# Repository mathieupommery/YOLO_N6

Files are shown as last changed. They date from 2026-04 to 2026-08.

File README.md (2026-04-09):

# Edge AI Vision Board (STM32N657)

This repository contains the design files for a high-performance, low-power Edge AI development board centered around the STM32N657 microcontroller. This project serves as a preliminary test platform for implementing high-speed differential and parallel buses (MIPI CSI-2 and Octo-SPI) in a compact form factor.

The primary objective is to execute YOLO-based object detection models efficiently, with data output and control interfacing managed via UART.

## Hardware Overview

### Board Images

| Front View | Back View |
| :--- | :--- |
|front|back|

### Core Components

* **MCU:** STM32N657IO (High-performance Arm Cortex-M7 with integrated NPU)
* **External Memory (PSRAM):** 64MB Octo-SPI DTR (running at 200MHz)
* **External Storage (Flash):** 256MB Octo-SPI
    * *Note: PSRAM and Flash are multiplexed on a HyperBus and connected via a daisy-chain topology.*

### Peripherals & Connectivity

* **Camera:** MIPI CSI connector, pin-compatible with the Raspberry Pi 5 camera.
* **Display:** Integrated ST7789 SPI display.
* **Storage:** MicroSD card connector, supporting up to 50MHz mode.
* **Debug:** Dedicated debug connector.
* **Data & Power:** USB-C connector.
* **Communication:** UART connector.

## Design Details & Constraints

This design was simulated using IBIS models to ensure signal integrity across all high-speed interfaces.

### Signal Integrity Metrics

* **MIPI CSI-2:**
    * Inter-pair skew: Matched to ±30ps.
    * Intra-pair skew: Matched to <0.1ps.
* **Octo-SPI:**
    * MCU to PSRAM : 8ps skew tolerance.
    * MCU to Flash : 70ps skew tolerance.
* **Layout:** The "3H rule" was strictly implemented throughout the entire board layout, including between meandering differential pairs, to minimize crosstalk.

## Project Roadmap

This project is a stepping stone towards developing more complex hardware. Following successful verification of this prototype, the next iteration is planned to feature LPDDR4 memory integrated with an STM32MP257F MPU in a similar form factor.

---

**Contact:** [Pommery Mathieu]

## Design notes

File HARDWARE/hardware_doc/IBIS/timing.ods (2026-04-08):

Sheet: Feuille1
PIN | AFTER(ESD) | BEFORE(ESD) | TOT | Correc for after esd trace | AFTER_RES_CLK
DAT0 | 105,47 | 22,57 | 128,04 | 137,12
DAT1 | 114,2 | 27,29 | 141,49 | 132,4
DAT2 | 129,12 | 30,57 | 159,69 | 129,12
DAT3 | 122,75 | 26,02 | 148,77 | 133,67
CLK | 115,2 | 15,96 | 131,16 | 133,05 | 10,68
CMD | 130,72 | 21,95 | 152,67 | 137,74

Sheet: Feuille2
CSI(PIN) | DIE ibs | FCU | BCU
D0N
D0P
D1N
D1P
CLKN
CLKP

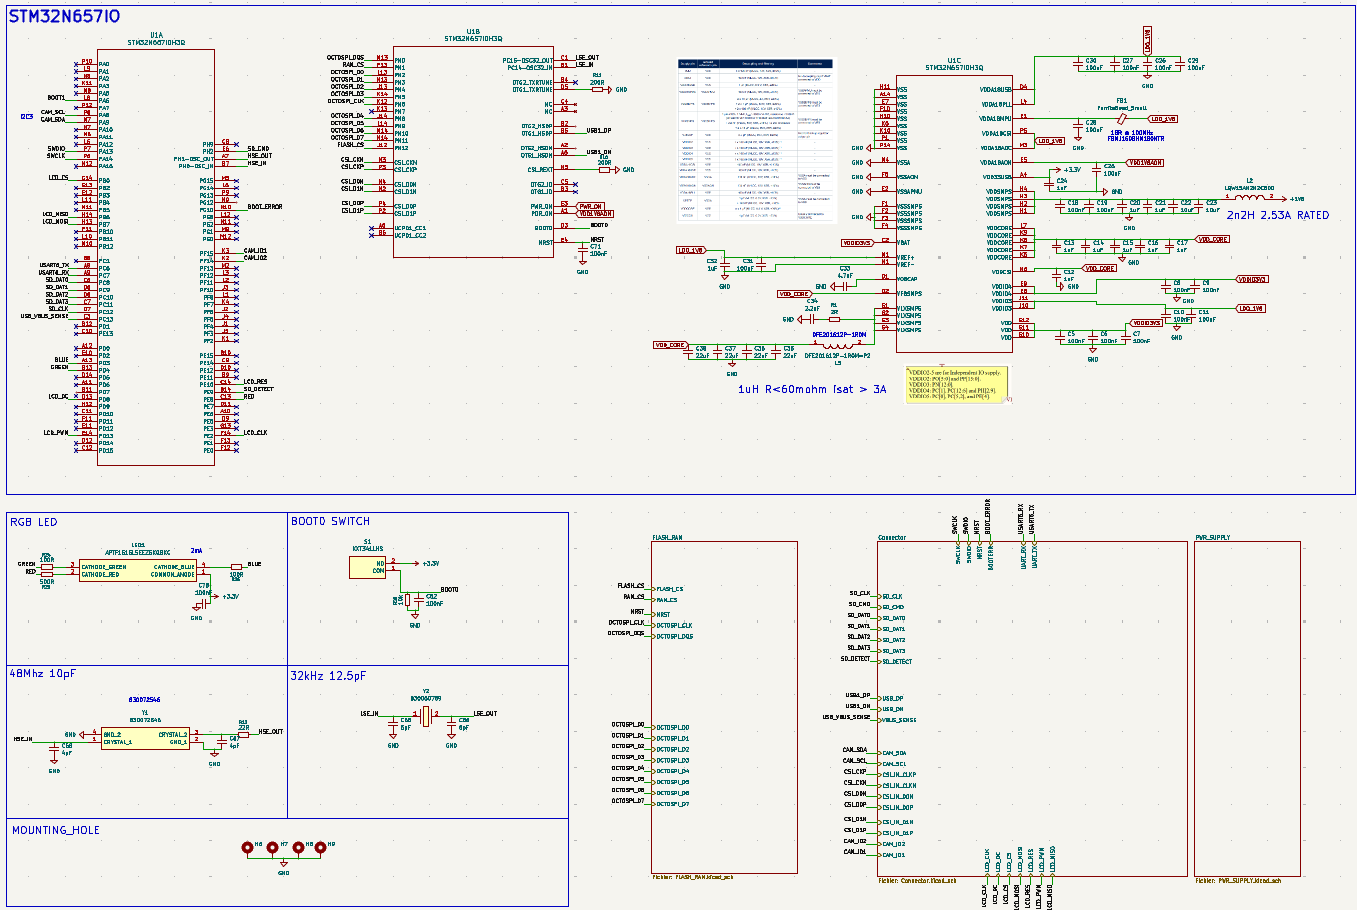
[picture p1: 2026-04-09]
DOC/stm32.png

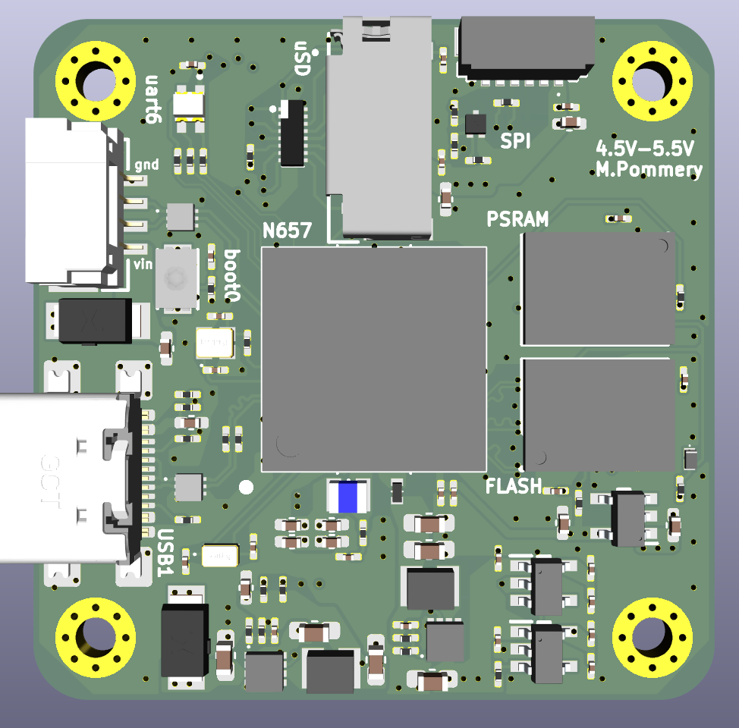
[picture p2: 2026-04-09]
DOC/front.png

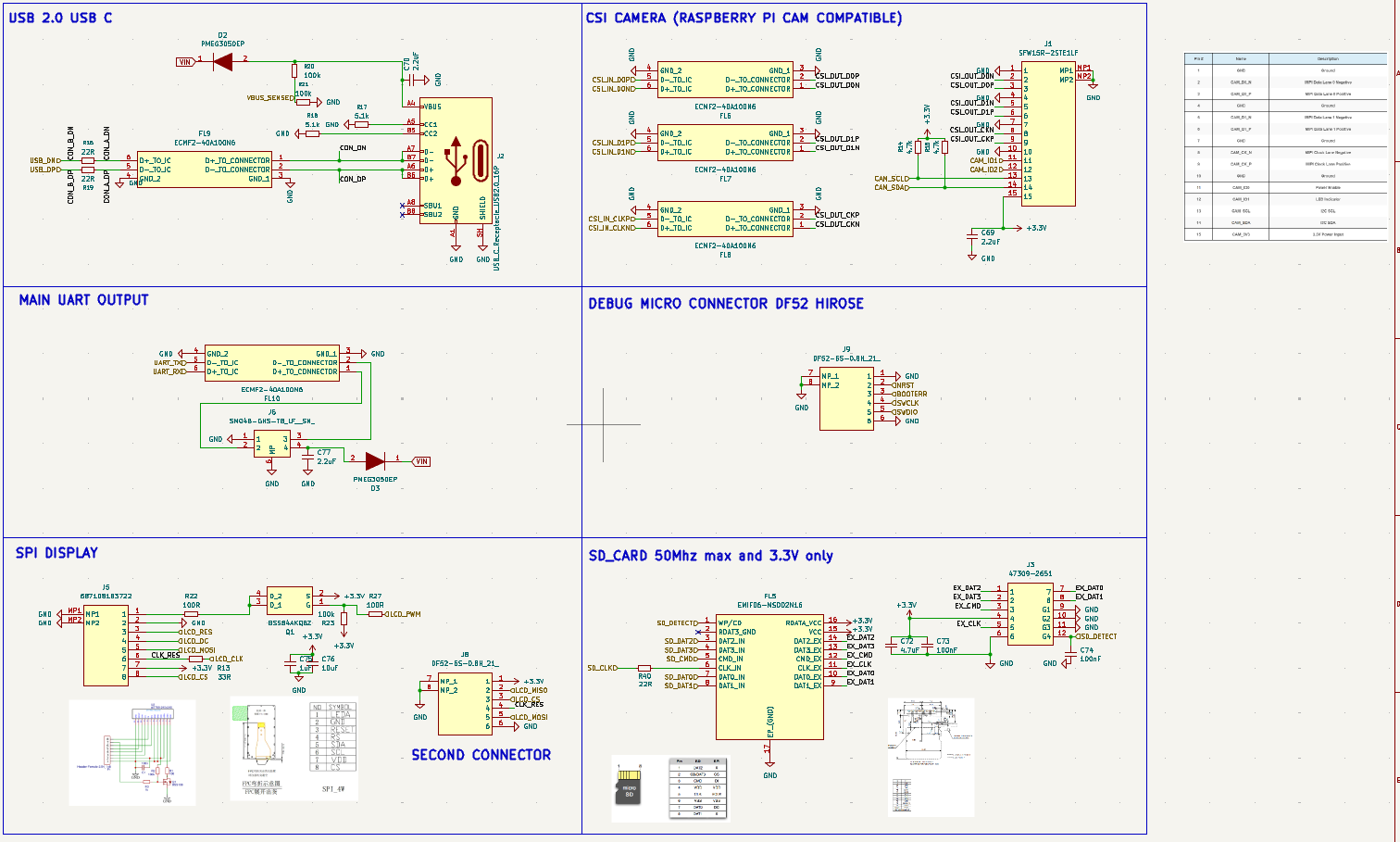
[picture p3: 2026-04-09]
DOC/conn.png

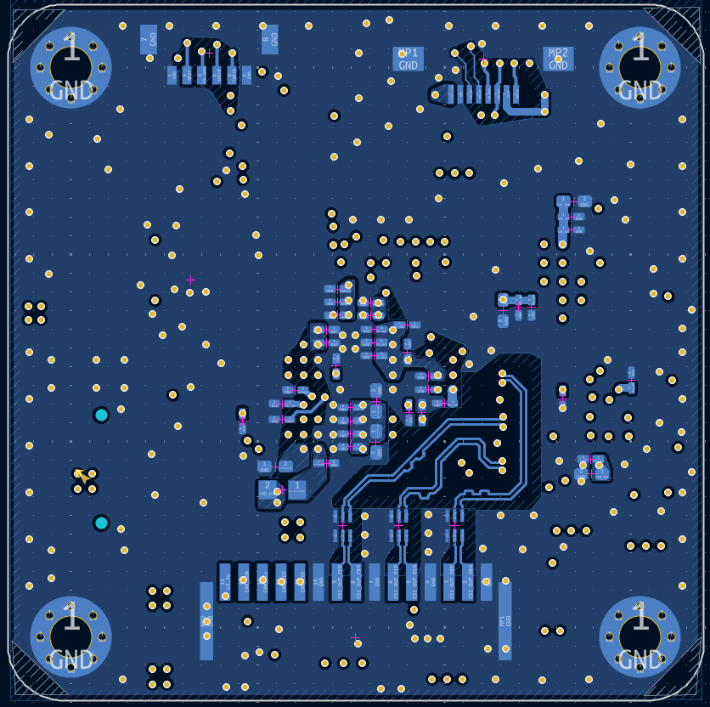
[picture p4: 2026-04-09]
DOC/l8.png

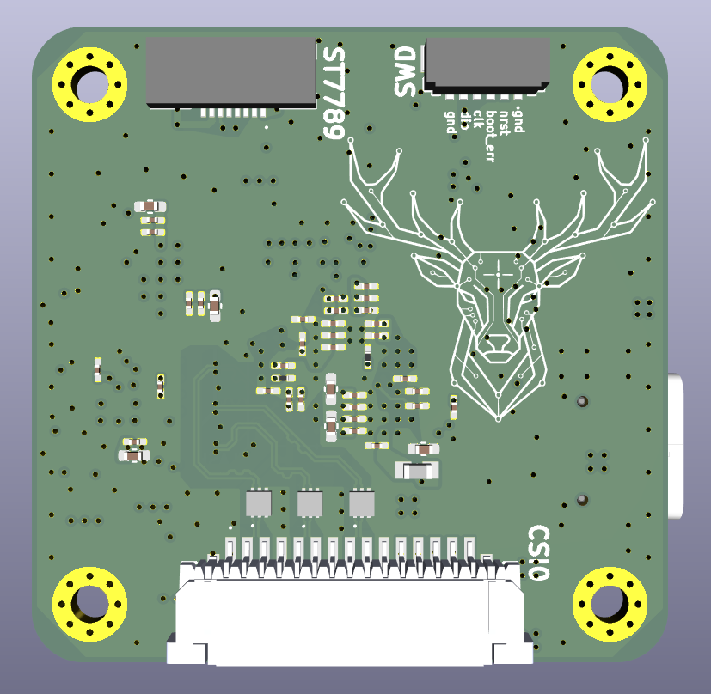
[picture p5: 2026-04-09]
DOC/back.png

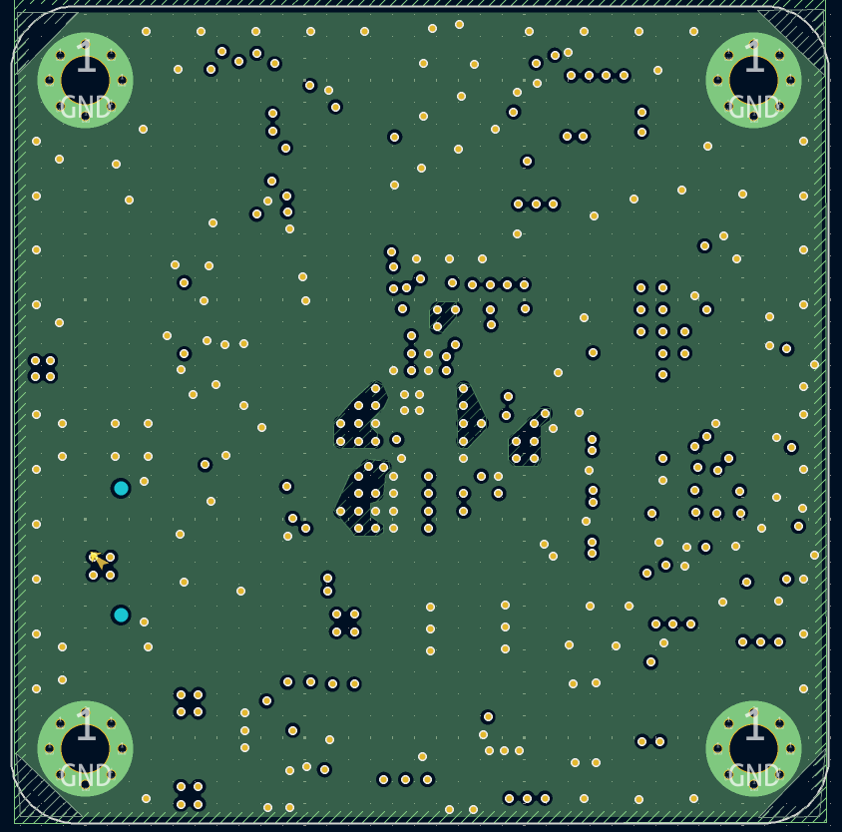
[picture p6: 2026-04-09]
DOC/l2.png

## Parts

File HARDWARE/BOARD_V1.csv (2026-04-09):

Reference | Qty | Value | Footprint
C5,C6,C7,C8,C9,C10,C11,C18,C19,C25,C26,C27,C28,C29,C30,C31,C55,C56,C57,C59,C61,C71,C73,C74,C78,C82 | 26 | 100nF | Capacitor_SMD:C_0201_0603Metric_Pad0.64x0.40mm_HandSolder
C12,C13,C14,C15,C16,C17,C20,C21,C24,C32,C39,C40,C41,C42,C43,C44,C63,C64,C75 | 19 | 1uF | Capacitor_SMD:C_0201_0603Metric_Pad0.64x0.40mm_HandSolder
C22,C23,C45,C46,C58,C60,C62,C76 | 8 | 10uF | Capacitor_SMD:C_0402_1005Metric_Pad0.74x0.62mm_HandSolder
C33,C72 | 2 | 4.7uF | Capacitor_SMD:C_0402_1005Metric_Pad0.74x0.62mm_HandSolder
C34 | 1 | 2.2nF | Capacitor_SMD:C_0201_0603Metric_Pad0.64x0.40mm_HandSolder
C35,C36,C37,C38 | 4 | 22uF | Capacitor_SMD:C_0402_1005Metric_Pad0.74x0.62mm_HandSolder
C47,C49,C50,C51,C53,C54 | 6 | 22uF | Capacitor_SMD:C_0603_1608Metric_Pad1.08x0.95mm_HandSolder
C48,C52 | 2 | 22pF | Capacitor_SMD:C_0201_0603Metric_Pad0.64x0.40mm_HandSolder
C65,C66 | 2 | 6pF | Capacitor_SMD:C_0201_0603Metric_Pad0.64x0.40mm_HandSolder
C67,C68 | 2 | 4pF | Capacitor_SMD:C_0201_0603Metric_Pad0.64x0.40mm_HandSolder
C69,C70,C77 | 3 | 2.2uF | Capacitor_SMD:C_0402_1005Metric_Pad0.74x0.62mm_HandSolder
C79,C80,C81 | 3 | 10nF | Capacitor_SMD:C_0201_0603Metric_Pad0.64x0.40mm_HandSolder
D1 | 1 | NSR05F30NXT5G | samacsys2:NSR05F30NXT5G
D2,D3 | 2 | PMEG3050EP | samacsys2:SOD4725X110N
FB1 | 1 | FBMJ1608HM180NTR | samacsys2:BEADC1608X100N
FL5 | 1 | EMIF06-MSD02N16 | samacsys2:EMIF06MSD02N16
FL6,FL7,FL8,FL9,FL10 | 5 | ECMF2-40A100N6 | samacsys2:ECMF240A100N6
IC1,IC5 | 2 | AP3441LSHE-7B | samacsys2:AP3441LSHE7B
IC2,IC3,IC4 | 3 | LDLN025M33R | samacsys2:SOT95P280X145-5N
IC6 | 1 | MX25UM25645GXDI00-T | samacsys2:BGA24C100P5X5_600X800X120
IC7 | 1 | APS51208N-OBR-BD | samacsys2:BGA24C100P5X5_600X800X120
J1 | 1 | SFW15R-2STE1LF | samacsys2:SFW15R2STE1LF
J2 | 1 | USB_C_Receptacle_USB2.0_16P | Connector_USB:USB_C_Receptacle_GCT_USB4110
J3 | 1 | 47309-2651 | samacsys:473092651
J5 | 1 | 687108183722 | samacsys:687108183722
J6 | 1 | SM04B-GHS-TB_LF__SN_ | SM04B-GHS-TB
J8,J9 | 2 | DF52-6S-0.8H_21_ | DF526S08H21
L1,L4 | 2 | 74479325207222 | samacsys2:74479325207222
L2 | 1 | LQW15AN2N2C80D | samacsys2:LQW15AN10NG80D
L5 | 1 | DFE201612P-1R0M=P2 | samacsys2:1286ASH1R0MP2
LED1 | 1 | APTF1616LSEEZGKQBKC | APTF1616SEEZGQBDC
Q1 | 1 | BSS84AKQBZ | samacsys:2N7002KQBZ
R1 | 1 | 2R | Resistor_SMD:R_0201_0603Metric_Pad0.64x0.40mm_HandSolder
R2,R6,R7,R20,R21,R23 | 6 | 100k | Resistor_SMD:R_0201_0603Metric_Pad0.64x0.40mm_HandSolder
R3 | 1 | 91k | Resistor_SMD:R_0201_0603Metric_Pad0.64x0.40mm_HandSolder
R4 | 1 | 20k | Resistor_SMD:R_0201_0603Metric_Pad0.64x0.40mm_HandSolder
R5 | 1 | 200k | Resistor_SMD:R_0201_0603Metric_Pad0.64x0.40mm_HandSolder
R8,R9,R28 | 3 | 10k | Resistor_SMD:R_0201_0603Metric_Pad0.64x0.40mm_HandSolder
R10,R11 | 2 | 200R | Resistor_SMD:R_0201_0603Metric_Pad0.64x0.40mm_HandSolder
R12,R16,R19,R40 | 4 | 22R | Resistor_SMD:R_0201_0603Metric_Pad0.64x0.40mm_HandSolder
R13 | 1 | 33R | Resistor_SMD:R_0201_0603Metric_Pad0.64x0.40mm_HandSolder
R14,R15 | 2 | 4.7k | Resistor_SMD:R_0201_0603Metric_Pad0.64x0.40mm_HandSolder
R17,R18 | 2 | 5.1k | Resistor_SMD:R_0201_0603Metric_Pad0.64x0.40mm_HandSolder
R22,R24,R26,R27 | 4 | 100R | Resistor_SMD:R_0201_0603Metric_Pad0.64x0.40mm_HandSolder
R25 | 1 | 500R | Resistor_SMD:R_0201_0603Metric_Pad0.64x0.40mm_HandSolder
S1 | 1 | KXT341LHS | KXT341LHS
U1 | 1 | STM32N657I0H3Q | STM32N657IO:VFBGA178_12X12_STM
Y1 | 1 | 830072546 | samacsys2:830072546
Y2 | 1 | 830050789 | samacsys2:830050789

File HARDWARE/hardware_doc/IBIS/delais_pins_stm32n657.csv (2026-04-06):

Pin | Signal | Inductance_nH | Capacitance_pF | Delay_ps
A1 | PDR_ON | 2.79 | 0.884 | 49.661
A2 | OTG2_HSDM | 2.894 | 0.907 | 51.226
A3 | NC | 3.026 | 0.897 | 52.101
A4 | VDD33USB | 1.346 | 1.759 | 48.658
A5 | OTG1_HSDM | 2.262 | 0.711 | 40.094
A6 | UCPD1_CC1 | 2.183 | 0.685 | 38.675
A7 | PH1-OSC_OUT | 1.998 | 0.684 | 36.964
A8 | PC6 | 2.307 | 0.695 | 40.046
A9 | PC7 | 2.13 | 0.703 | 38.692
A10 | PE6 | 2.346 | 0.731 | 41.403
A11 | PD6 | 2.614 | 0.804 | 45.836
A12 | PD0 | 2.908 | 0.922 | 51.776
A13 | PD3 | 3.172 | 0.97 | 55.483
A14 | VSS | 0.046 | 58.495 | 52.064
B1 | PC14 | 2.793 | 0.876 | 49.462
B2 | OTG2_HSDP | 2.677 | 0.89 | 48.821
B3 | OTG1_ID | 2.639 | 0.924 | 49.376
B4 | OTG2_TXRTUNE | 1.941 | 0.669 | 36.049
B5 | OTG1_HSDP | 2.207 | 0.696 | 39.191
B6 | UCPD1_CC2 | 1.665 | 0.613 | 31.952
B7 | PH0-OSC_IN | 1.582 | 0.568 | 29.985
B8 | PC1 | 1.982 | 0.651 | 35.924
B9 | PE11 | 1.847 | 0.59 | 33.018
B10 | PE15 | 2.157 | 0.666 | 37.908
B11 | PD7 | 2.215 | 0.72 | 39.934
B12 | PD1 | 2.146 | 0.737 | 39.769
B13 | PD4 | 2.802 | 0.874 | 49.494
B14 | PE9 | 3.05 | 0.943 | 53.644
C1 | PC15-OSC32_OUT | 2.788 | 0.87 | 49.257
C2 | VBAT | 2.11 | 0.774 | 40.407
C3 | PC13 | 1.901 | 0.701 | 36.509
C4 | NC | 1.477 | 0.658 | 31.168
C5 | OTG2_ID | 1.265 | 0.537 | 26.065
C6 | PC8 | 2.797 | 0.814 | 47.729
C7 | PC11 | 2.052 | 0.609 | 35.356
C8 | PH9 | 1.474 | 0.525 | 27.813
C9 | PE14 | 1.582 | 0.603 | 30.89
C10 | PE13 | 1.579 | 0.52 | 28.66
C11 | PD10 | 1.724 | 0.612 | 32.489
C12 | PD15 | 2.107 | 0.708 | 38.637
C13 | PE8 | 2.451 | 0.773 | 43.533
C14 | PE10 | 2.737 | 0.862 | 48.562
D1 | V08CAP | 2.209 | 0.8 | 42.041
D2 | VFBSMPS | 2.669 | 0.898 | 48.949
D3 | BOOT0 | 1.459 | 0.491 | 26.777
D4 | VDDA18USB | 1.107 | 1.38 | 39.093
D5 | OTG1_TXRTUNE | 2.055 | 0.696 | 37.806
D6 | PC9 | 2.959 | 0.859 | 50.402
D7 | PC12 | 1.824 | 0.58 | 32.529
D8 | PC10 | 0.924 | 0.415 | 19.581
D9 | PE5 | 1.376 | 0.535 | 27.141
D10 | PE12 | 1.227 | 0.504 | 24.856
D11 | PE7 | 1.39 | 0.517 | 26.81
D12 | PD14 | 1.715 | 0.576 | 31.413
D13 | PD8 | 2.038 | 0.655 | 36.541
D14 | PD5 | 2.558 | 0.791 | 44.974
E1 | VDDA18PMU | 2.027 | 0.757 | 39.167
E2 | VSSAPMU | 1.583 | 0.645 | 31.942
E3 | PWR_ON | 1.204 | 0.47 | 23.794
E4 | NRST | 0.898 | 0.41 | 19.192
E5 | VDDA18AON | 0.281 | 4.532 | 35.69
E6 | PH2 | 2.586 | 0.732 | 43.522
E8 | VDDIO4 | 0.196 | 0.708 | 11.767
E10 | PD2 | 0.786 | 0.401 | 17.756
E11 | PD12 | 0.99 | 0.411 | 20.18
E12 | PB3 | 1.732 | 0.615 | 32.626
E13 | PB2 | 2.019 | 0.666 | 36.656
E14 | PD13 | 2.575 | 0.812 | 45.736
F1 | VSSSMPS | 0.317 | 1.553 | 22.188
F5 | VSSAON | 0.936 | 0.457 | 20.678
F11 | PD11 | 1.762 | 0.654 | 33.936
F12 | PE0 | 1.586 | 0.625 | 31.493
F13 | PE1 | 1.683 | 0.606 | 31.94
F14 | PE2 | 2.121 | 0.693 | 38.331
G1 | VLXSMPS | 0.273 | 1.437 | 19.818
G10 | VDD | 0.395 | 3.614 | 37.779
G13 | PE3 | 1.577 | 0.559 | 29.681
G14 | PB0 | 1.936 | 0.655 | 35.611
H1 | VDDSMPS | 0.264 | 1.433 | 19.442
H12 | PD9 | 0.916 | 0.423 | 19.686
H13 | PB7 | 1.487 | 0.557 | 28.777
H14 | PB6 | 2.015 | 0.682 | 37.085
J1 | PF4 | 1.762 | 0.622 | 33.101
J2 | PF6 | 1.603 | 0.567 | 30.151
J3 | PF10 | 1.138 | 0.43 | 22.119
J4 | PF5 | 0.678 | 0.298 | 14.201
J5 | PF3 | 0.907 | 0.435 | 19.873
J10 | VDDIO3 | 0.53 | 1.583 | 28.956
J12 | PN12 | 4.208 | 1.211 | 71.388
J13 | PN4 | 2.346 | 0.698 | 40.469
J14 | PN8 | 3.919 | 1.097 | 65.579
K1 | PF2 | 2.15 | 0.683 | 38.314
K2 | PF14 | 1.753 | 0.591 | 32.204
K3 | PF15 | 1.272 | 0.472 | 24.493
K4 | PF7 | 1.05 | 0.452 | 21.794
K6 | VDDCORE | 0.081 | 6.305 | 22.612
K11 | PA3 | 2.747 | 0.911 | 50.041
K12 | PN6 | 2.077 | 0.703 | 38.226
K13 | PN7 | 2.776 | 0.828 | 47.95
K14 | PN5 | 2.641 | 0.776 | 45.27
L1 | PF8 | 2.243 | 0.694 | 39.469
L2 | PF11 | 1.908 | 0.614 | 34.244
L3 | PF12 | 1.404 | 0.473 | 25.767
L4 | VDDA18PLL | 3.343 | 1.393 | 68.255
L5 | PG14 | 2.257 | 0.725 | 40.461
L6 | PA12 | 1.335 | 0.537 | 26.781
L8 | PA6 | 1.231 | 0.542 | 25.841
L9 | PA1 | 1.96 | 0.663 | 36.054
L10 | PB11 | 2.297 | 0.719 | 40.632
L11 | PB4 | 2.864 | 0.831 | 48.798
L12 | PG8 | 2.902 | 0.904 | 51.211
L13 | PN2 | 2.336 | 0.703 | 40.521
L14 | PN9 | 3.226 | 0.925 | 54.637
M1 | VREFP | 2.652 | 0.871 | 48.057
M2 | PF13 | 2.045 | 0.617 | 35.518
M3 | VDDA18ADC | 1.123 | 1.118 | 35.44
M4 | VSSA | 1.033 | 0.976 | 31.742
M5 | PG15 | 2.12 | 0.715 | 38.924
M6 | PA11 | 1.414 | 0.52 | 27.122
M7 | PA9 | 1.132 | 0.44 | 22.317
M8 | PA5 | 1.516 | 0.586 | 29.811
M9 | PG1 | 1.931 | 0.655 | 35.562
M10 | PB12 | 2.193 | 0.68 | 38.607
M11 | PB5 | 2.716 | 0.815 | 47.054
M12 | PG0 | 2.79 | 0.811 | 47.563
M13 | PN0 | 3.065 | 0.842 | 50.788
M14 | PN10 | 3.031 | 0.888 | 51.883
N1 | VREFM | 2.44 | 0.857 | 45.72
N2 | CSI_D1N | 2.302 | 0.836 | 43.868
N3 | CSI_CKN | 2.325 | 0.802 | 43.183
N4 | CSI_D0N | 2.183 | 0.747 | 40.392
N5 | CSI_REXT | 1.929 | 0.685 | 36.34
N6 | VDDCSI | 1.488 | 0.63 | 30.609
N7 | PA10 | 1.702 | 0.578 | 31.38
N8 | PA2 | 1.861 | 0.675 | 35.447
N9 | PG12 | 2.067 | 0.646 | 36.532
N10 | PG10 | 2.347 | 0.769 | 42.493
N11 | PG2 | 2.558 | 0.806 | 45.411
N12 | PA15 | 2.854 | 0.814 | 48.196
N13 | PN3 | 4.025 | 1.156 | 68.203
N14 | PN11 | 2.794 | 0.919 | 50.668
P2 | CSI_D1P | 2.407 | 0.84 | 44.973
P3 | CSI_CKP | 2.327 | 0.819 | 43.639
P4 | CSI_D0P | 2.18 | 0.772 | 41.035
P5 | VDDA18CSI | 1.983 | 0.768 | 39.027
P6 | PA14 | 1.904 | 0.663 | 35.532
P7 | PA13 | 2.264 | 0.732 | 40.707
P8 | PA8 | 2.117 | 0.669 | 37.64
P9 | PG13 | 2.264 | 0.69 | 39.513
P10 | PA0 | 2.573 | 0.762 | 44.283
P11 | PB10 | 2.606 | 0.795 | 45.51
P12 | PA7 | 3.138 | 0.876 | 52.421
P13 | PN1 | 3.535 | 0.981 | 58.875

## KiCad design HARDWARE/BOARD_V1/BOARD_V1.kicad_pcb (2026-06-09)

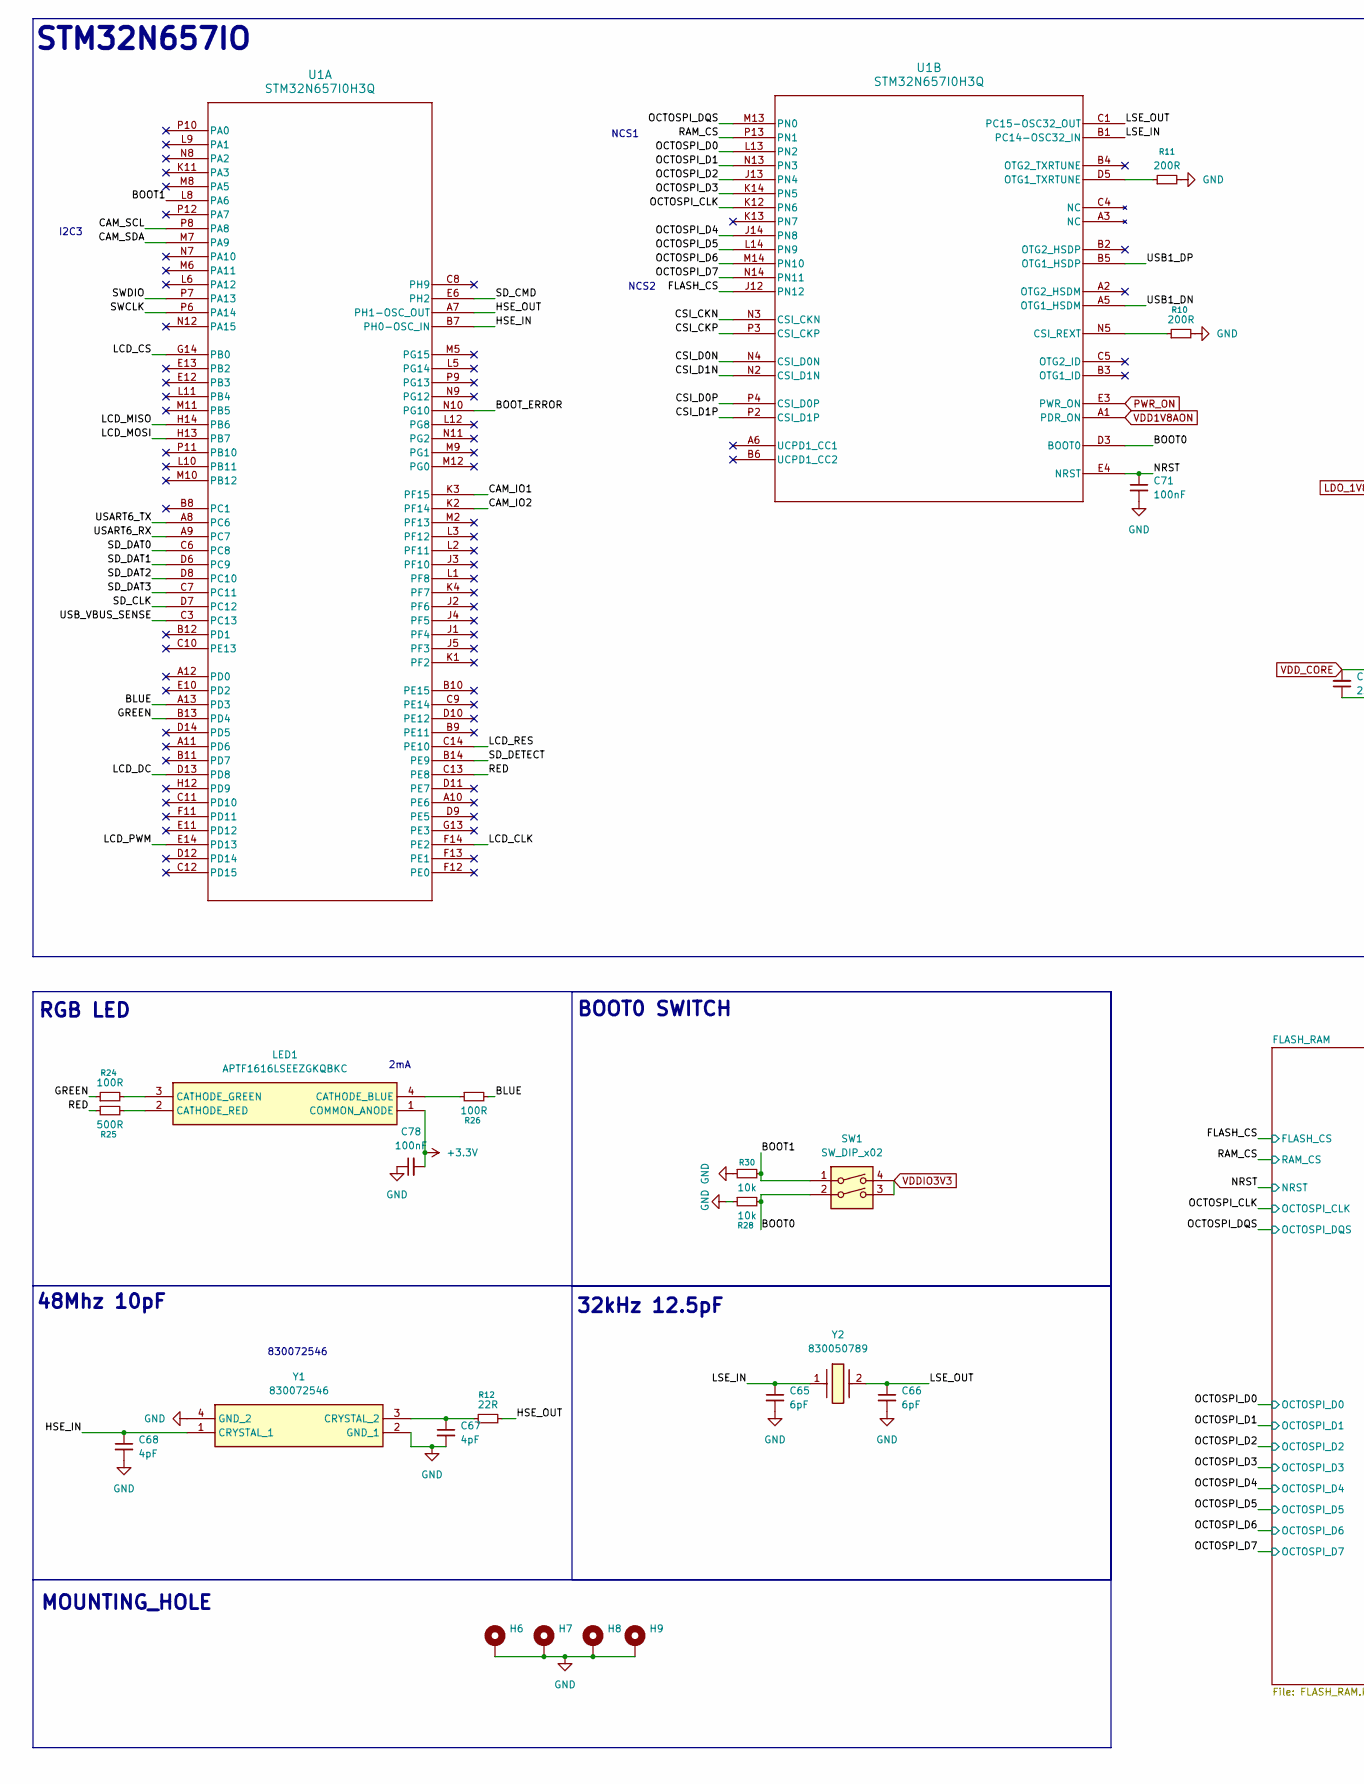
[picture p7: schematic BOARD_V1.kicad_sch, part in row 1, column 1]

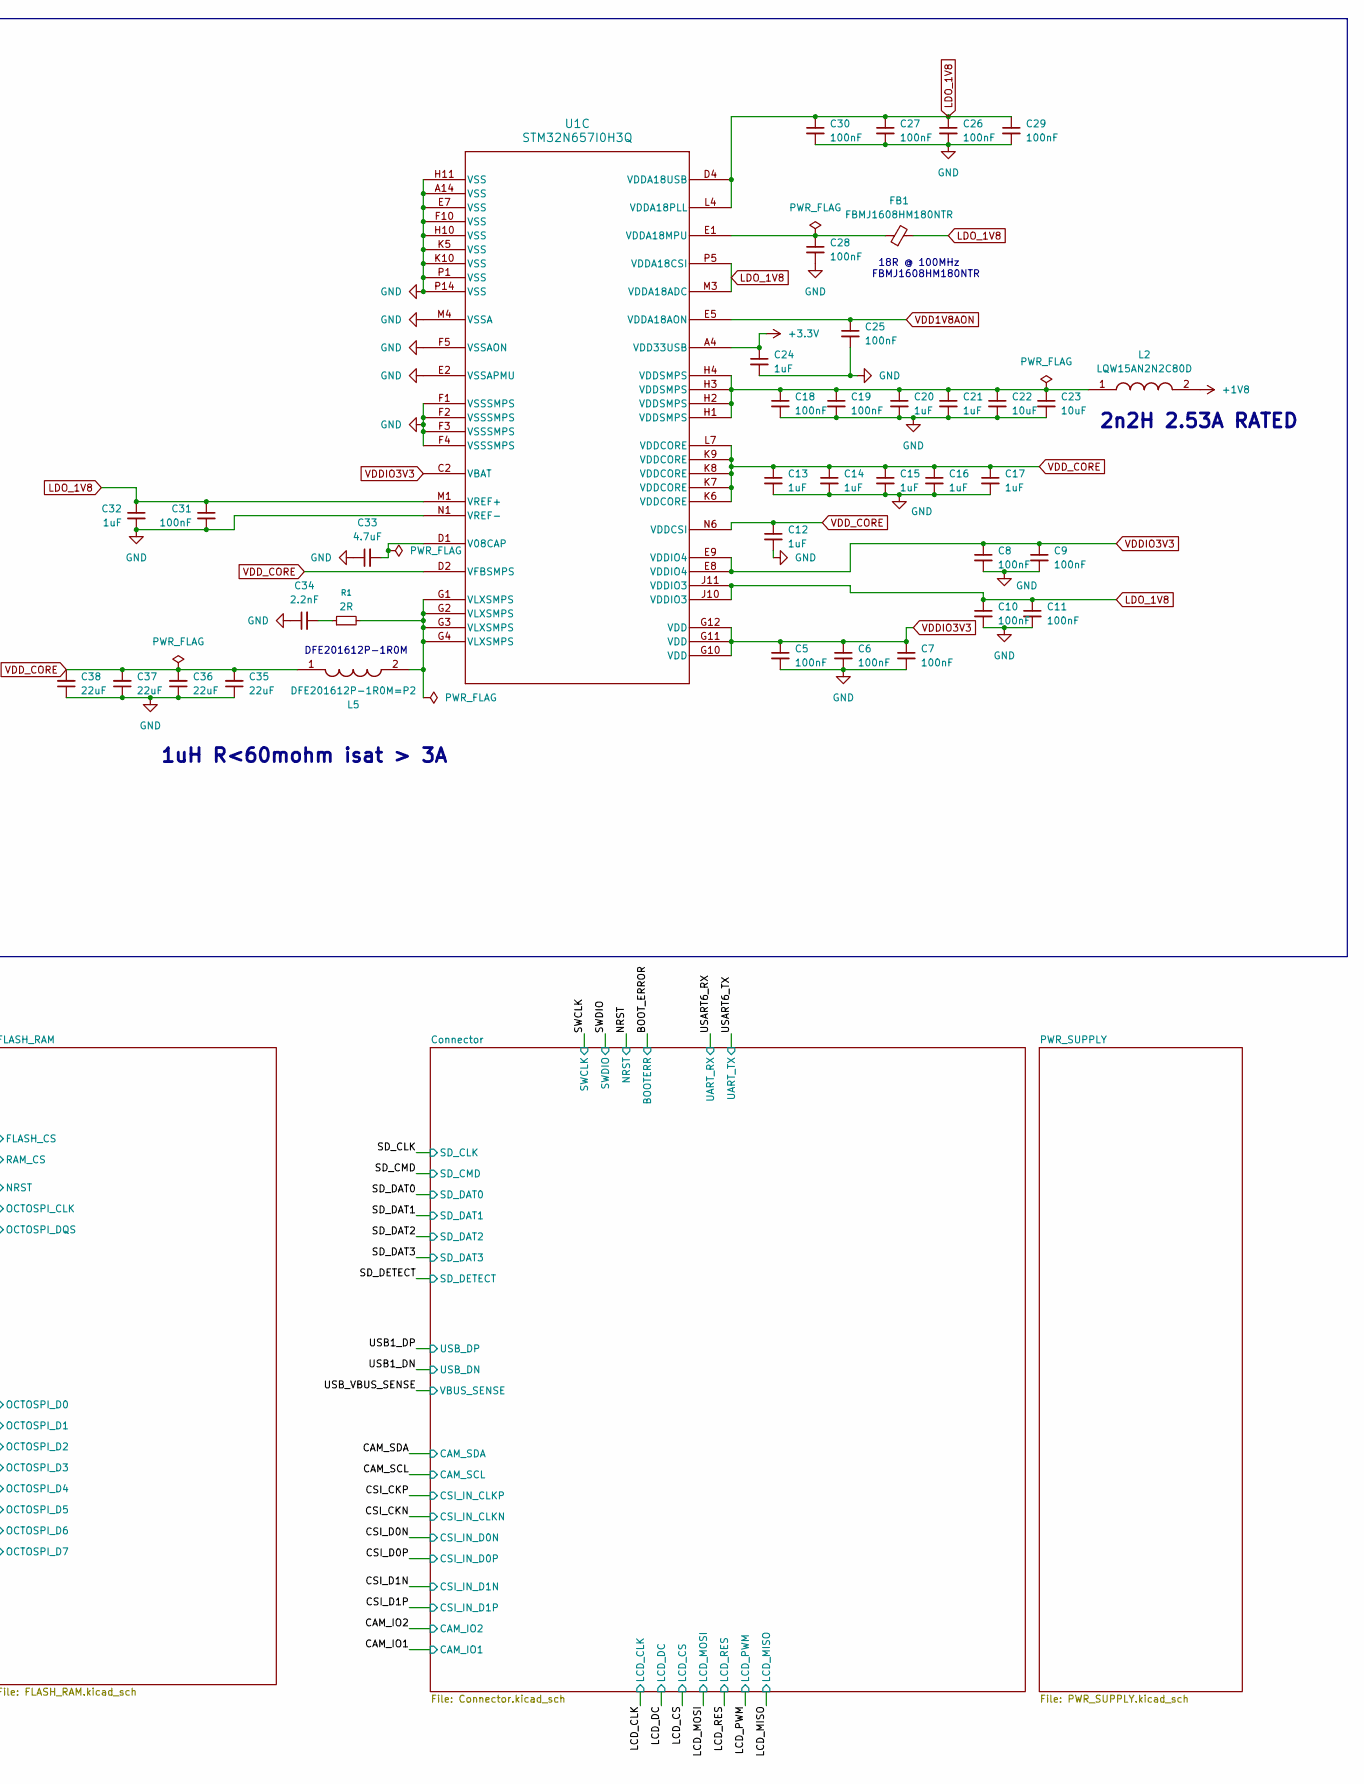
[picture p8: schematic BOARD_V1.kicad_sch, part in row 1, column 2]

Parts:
C5, C6, C7, C8, C9, C10, C11, C18, C19, C25, C26, C27, C28, C29, C30, C31, C71, C78: 100nF; C_0201_0603Metric_Pad0.64x0.40mm_HandSolder
C12, C13, C14, C15, C16, C17, C20, C21, C24, C32: 1uF; C_0201_0603Metric_Pad0.64x0.40mm_HandSolder
C22, C23: 10uF; C_0402_1005Metric_Pad0.74x0.62mm_HandSolder
C33: 4.7uF; C_0402_1005Metric_Pad0.74x0.62mm_HandSolder
C34: 2.2nF; C_0201_0603Metric_Pad0.64x0.40mm_HandSolder
C35, C36, C37, C38: 22uF; C_0402_1005Metric_Pad0.74x0.62mm_HandSolder
C65, C66: 6pF; C_0201_0603Metric_Pad0.64x0.40mm_HandSolder
C67, C68: 4pF; C_0201_0603Metric_Pad0.64x0.40mm_HandSolder
FB1: FBMJ1608HM180NTR; BEADC1608X100N; Mouser Part Number 963-FBMJ1608HM180NTR
H6, H7, H8, H9: MountingHole_Pad_MP; MountingHole_2.2mm_M2_Pad_Via
L2: LQW15AN2N2C80D; LQW15AN10NG80D; Manufacturer_Part_Number LQW15AN2N2C80D; Mouser Part Number 81-LQW15AN2N2C80D
L5: DFE201612P-1R0M=P2; 1286ASH1R0MP2; Manufacturer_Part_Number DFE201612P-1R0M=P2; Mouser Part Number 81-DFE201612P-1R0MP2
LED1: APTF1616LSEEZGKQBKC; APTF1616SEEZGQBDC; Manufacturer_Part_Number APTF1616LSEEZGKQBKC; Mouser Part Number 604-APTF1616LSEEZGKQ
R1: 2R; R_0201_0603Metric_Pad0.64x0.40mm_HandSolder
R10, R11: 200R; R_0201_0603Metric_Pad0.64x0.40mm_HandSolder
R12: 22R; R_0201_0603Metric_Pad0.64x0.40mm_HandSolder
R24, R26: 100R; R_0201_0603Metric_Pad0.64x0.40mm_HandSolder
R25: 500R; R_0201_0603Metric_Pad0.64x0.40mm_HandSolder
R28, R30: 10k; R_0201_0603Metric_Pad0.64x0.40mm_HandSolder
SW1: SW_DIP_x02; SW_DIP_SPSTx02_Slide_KingTek_DSHP02TJ_W5.25mm_P1.27mm_JPin
U1: STM32N657I0H3Q; VFBGA178_12X12_STM
Y1: 830072546; Manufacturer_Part_Number 830072546; Mouser Part Number 710-830072546
Y2: 830050789; Manufacturer_Part_Number 830050789; Mouser Part Number 710-830050789

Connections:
+1V8: L2.2; also elsewhere on the board
+3.3V: C24.1, C78.2, LED1.1 (COMMON_ANODE), U1.A4 (VDD33USB); also elsewhere on the board
/BLUE: R26.2, U1.A13 (PD3)
/BOOT0: R28.2, SW1.2, U1.D3 (BOOT0)
/BOOT1: R30.2, SW1.1, U1.L8 (PA6)
/BOOT_ERROR: U1.N10 (PG10); also elsewhere on the board
/CAM_IO1: U1.K3 (PF15); also elsewhere on the board
/CAM_IO2: U1.K2 (PF14); also elsewhere on the board
/CAM_SCL: U1.P8 (PA8); also elsewhere on the board
/CAM_SDA: U1.M7 (PA9); also elsewhere on the board
/CSI_CKN: U1.N3 (CSI_CKN); also elsewhere on the board
/CSI_CKP: U1.P3 (CSI_CKP); also elsewhere on the board
/CSI_D0N: U1.N4 (CSI_D0N); also elsewhere on the board
/CSI_D0P: U1.P4 (CSI_D0P); also elsewhere on the board
/CSI_D1N: U1.N2 (CSI_D1N); also elsewhere on the board
/CSI_D1P: U1.P2 (CSI_D1P); also elsewhere on the board
/FLASH_CS: U1.J12 (PN12); also elsewhere on the board
/GREEN: R24.1, U1.B13 (PD4)
/HSE_IN: C68.1, U1.B7 (PH0-OSC_IN), Y1.1 (CRYSTAL_1)
/HSE_OUT: R12.2, U1.A7 (PH1-OSC_OUT)
/LCD_CLK: U1.F14 (PE2); also elsewhere on the board
/LCD_CS: U1.G14 (PB0); also elsewhere on the board
/LCD_DC: U1.D13 (PD8); also elsewhere on the board
/LCD_MISO: U1.H14 (PB6); also elsewhere on the board
/LCD_MOSI: U1.H13 (PB7); also elsewhere on the board
/LCD_PWM: U1.E14 (PD13); also elsewhere on the board
/LCD_RES: U1.C14 (PE10); also elsewhere on the board
/LSE_IN: C65.1, U1.B1 (PC14-OSC32_IN), Y2.1
/LSE_OUT: C66.1, U1.C1 (PC15-OSC32_OUT), Y2.2
/NRST: C71.1, U1.E4 (NRST); also elsewhere on the board
/OCTOSPI_CLK: U1.K12 (PN6); also elsewhere on the board
/OCTOSPI_D0: U1.L13 (PN2); also elsewhere on the board
/OCTOSPI_D1: U1.N13 (PN3); also elsewhere on the board
/OCTOSPI_D2: U1.J13 (PN4); also elsewhere on the board
/OCTOSPI_D3: U1.K14 (PN5); also elsewhere on the board
/OCTOSPI_D4: U1.J14 (PN8); also elsewhere on the board
/OCTOSPI_D5: U1.L14 (PN9); also elsewhere on the board
/OCTOSPI_D6: U1.M14 (PN10); also elsewhere on the board
/OCTOSPI_D7: U1.N14 (PN11); also elsewhere on the board
/OCTOSPI_DQS: U1.M13 (PN0); also elsewhere on the board
/RAM_CS: U1.P13 (PN1); also elsewhere on the board
/RED: R25.1, U1.C13 (PE8)
/SD_CLK: U1.D7 (PC12); also elsewhere on the board
/SD_CMD: U1.E6 (PH2); also elsewhere on the board
/SD_DAT0: U1.C6 (PC8); also elsewhere on the board
/SD_DAT1: U1.D6 (PC9); also elsewhere on the board
/SD_DAT2: U1.D8 (PC10); also elsewhere on the board
/SD_DAT3: U1.C7 (PC11); also elsewhere on the board
/SD_DETECT: U1.B14 (PE9); also elsewhere on the board
/SWCLK: U1.P6 (PA14); also elsewhere on the board
/SWDIO: U1.P7 (PA13); also elsewhere on the board
/USART6_RX: U1.A9 (PC7); also elsewhere on the board
/USART6_TX: U1.A8 (PC6); also elsewhere on the board
/USB1_DN: U1.A5 (OTG1_HSDM); also elsewhere on the board
/USB1_DP: U1.B5 (OTG1_HSDP); also elsewhere on the board
/USB_VBUS_SENSE: U1.C3 (PC13); also elsewhere on the board
GND: C5.2, C6.2, C7.2, C8.2, C9.2, C10.2, C11.2, C12.2, C13.2, C14.2, C15.2, C16.2, C17.2, C18.2, C19.2, C20.2, C21.2, C22.2, C23.2, C24.2, C25.2, C26.2, C27.2, C28.2, C29.2, C30.2, C31.2, C32.2, C33.1, C34.1, C35.1, C36.1, C37.1, C38.1, C65.2, C66.2, C67.2, C68.2, C71.2, C78.1, H6.1 (1_1), H7.1 (1_1), H8.1 (1_1), H9.1 (1_1), R10.2, R11.2, R28.1, R30.1, U1.A14 (VSS), U1.E2 (VSSAPMU), U1.E7 (VSS), U1.F1 (VSSSMPS), U1.F2 (VSSSMPS), U1.F3 (VSSSMPS), U1.F4 (VSSSMPS), U1.F5 (VSSAON), U1.F10 (VSS), U1.H10 (VSS), U1.H11 (VSS), U1.K5 (VSS), U1.K10 (VSS), U1.M4 (VSSA), U1.N1 (VREF-), U1.P1 (VSS), U1.P14 (VSS), Y1.2 (GND_1), Y1.4 (GND_2); also elsewhere on the board
LDO_1V8: C10.1, C11.1, C26.1, C27.1, C29.1, C30.1, C31.1, C32.1, FB1.2, U1.D4 (VDDA18USB), U1.J10 (VDDIO3), U1.J11 (VDDIO3), U1.L4 (VDDA18PLL), U1.M1 (VREF+), U1.M3 (VDDA18ADC), U1.P5 (VDDA18CSI); also elsewhere on the board
unnamed: C18.1, C19.1, C20.1, C21.1, C22.1, C23.1, L2.1, U1.H1 (VDDSMPS), U1.H2 (VDDSMPS), U1.H3 (VDDSMPS), U1.H4 (VDDSMPS)
unnamed: C34.2, R1.1
unnamed: L5.2, R1.2, U1.G1 (VLXSMPS), U1.G2 (VLXSMPS), U1.G3 (VLXSMPS), U1.G4 (VLXSMPS)
unnamed: LED1.4 (CATHODE_BLUE), R26.1
unnamed: LED1.3 (CATHODE_GREEN), R24.2
unnamed: LED1.2 (CATHODE_RED), R25.2
unnamed: R10.1, U1.N5 (CSI_REXT)
unnamed: R11.1, U1.D5 (OTG1_TXRTUNE)
unnamed: C33.2, U1.D1 (V08CAP)
unnamed: C28.1, FB1.1, U1.E1 (VDDA18MPU)
unnamed: C67.1, R12.1, Y1.3 (CRYSTAL_2)
PWR_ON: U1.E3 (PWR_ON); also elsewhere on the board
VDD1V8AON: C25.1, U1.A1 (PDR_ON), U1.E5 (VDDA18AON); also elsewhere on the board
VDDIO3V3: C5.1, C6.1, C7.1, C8.1, C9.1, SW1.3, SW1.4, U1.C2 (VBAT), U1.E8 (VDDIO4), U1.E9 (VDDIO4), U1.G10 (VDD), U1.G11 (VDD), U1.G12 (VDD); also elsewhere on the board
VDD_CORE: C12.1, C13.1, C14.1, C15.1, C16.1, C17.1, C35.2, C36.2, C37.2, C38.2, L5.1, U1.D2 (VFBSMPS), U1.K6 (VDDCORE), U1.K7 (VDDCORE), U1.K8 (VDDCORE), U1.K9 (VDDCORE), U1.L7 (VDDCORE), U1.N6 (VDDCSI)

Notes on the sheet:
FBMJ1608HM180NTR
2mA
830072546
MOUNTING_HOLE
I2C3
48Mhz 10pF
1uH R<60mohm isat > 3A
RGB LED
32kHz 12.5pF
BOOT0 SWITCH
STM32N657IO
18R @ 100MHz
NCS1
DFE201612P-1R0M
NCS2
2n2H 2.53A RATED

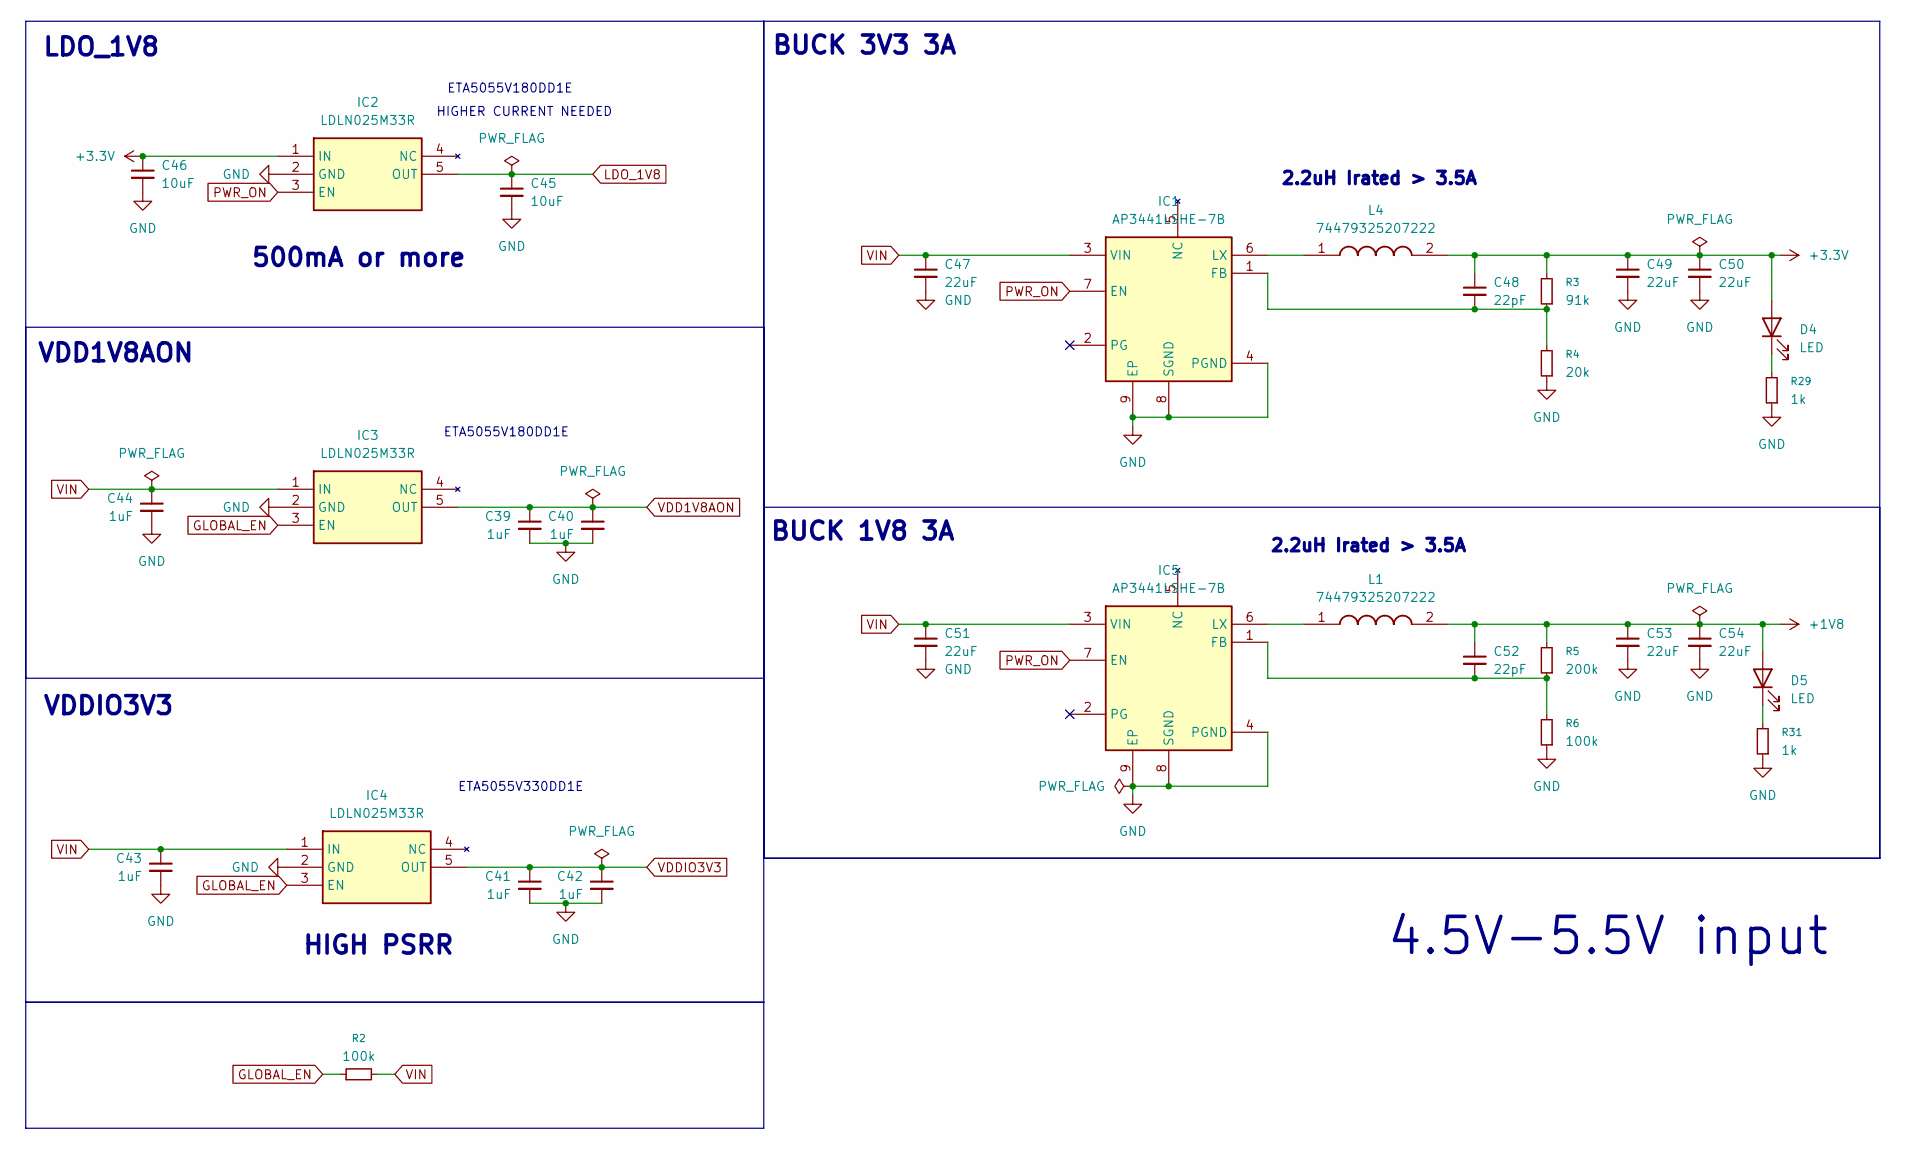
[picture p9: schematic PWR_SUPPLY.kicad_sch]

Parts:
C39, C40, C41, C42, C43, C44: 1uF; C_0201_0603Metric_Pad0.64x0.40mm_HandSolder
C45, C46: 10uF; C_0402_1005Metric_Pad0.74x0.62mm_HandSolder
C47, C49, C50, C51, C53, C54: 22uF; C_0603_1608Metric_Pad1.08x0.95mm_HandSolder
C48, C52: 22pF; C_0201_0603Metric_Pad0.64x0.40mm_HandSolder
D4, D5: LED; LED_0402_1005Metric
IC1, IC5: AP3441LSHE-7B; AP3441LSHE7B; Manufacturer_Part_Number AP3441LSHE-7B; Mouser Part Number 621-AP3441LSHE-7B
IC2, IC3, IC4: LDLN025M33R; SOT95P280X145-5N; Manufacturer_Part_Number LDLN025M33R; Mouser Part Number 511-LDLN025M33R 595-TLV75518PDBVR 511-L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
L1, L4: 74479325207222; Manufacturer_Part_Number 74479325207222
R2, R6: 100k; R_0201_0603Metric_Pad0.64x0.40mm_HandSolder
R3: 91k; R_0201_0603Metric_Pad0.64x0.40mm_HandSolder
R4: 20k; R_0201_0603Metric_Pad0.64x0.40mm_HandSolder
R5: 200k; R_0201_0603Metric_Pad0.64x0.40mm_HandSolder
R29, R31: 1k; R_0201_0603Metric_Pad0.64x0.40mm_HandSolder

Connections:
+1V8: C52.1, C53.1, C54.1, D5.2 (A), L1.2, R5.2; also elsewhere on the board
+3.3V: C46.1, C48.1, C49.1, C50.1, D4.2 (A), IC2.1 (IN), L4.2, R3.2; also elsewhere on the board
GLOBAL_EN: IC3.3 (EN), IC4.3 (EN), R2.1
GND: C39.2, C40.2, C41.2, C42.2, C43.2, C44.2, C45.2, C46.2, C47.2, C49.2, C50.2, C51.2, C53.2, C54.2, IC1.4 (PGND), IC1.8 (SGND), IC1.9 (EP), IC2.2 (GND), IC3.2 (GND), IC4.2 (GND), IC5.4 (PGND), IC5.8 (SGND), IC5.9 (EP), R4.1, R6.1, R29.1, R31.1; also elsewhere on the board
LDO_1V8: C45.1, IC2.5 (OUT); also elsewhere on the board
unnamed: D4.1 (K), R29.2
unnamed: D5.1 (K), R31.2
unnamed: C48.2, IC1.1 (FB), R3.1, R4.2
unnamed: IC1.6 (LX), L4.1
unnamed: C52.2, IC5.1 (FB), R5.1, R6.2
unnamed: IC5.6 (LX), L1.1
PWR_ON: IC1.7 (EN), IC2.3 (EN), IC5.7 (EN); also elsewhere on the board
VDD1V8AON: C39.1, C40.1, IC3.5 (OUT); also elsewhere on the board
VDDIO3V3: C41.1, C42.1, IC4.5 (OUT); also elsewhere on the board
VIN: C43.1, C44.1, C47.1, C51.1, IC1.3 (VIN), IC3.1 (IN), IC4.1 (IN), IC5.3 (VIN), R2.2; also elsewhere on the board

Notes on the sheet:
2.2uH Irated > 3.5A
BUCK 1V8 3A
4.5V-5.5V input
LDO_1V8
HIGH PSRR
BUCK 3V3 3A
ETA5055V180DD1E
ETA5055V330DD1E
VDDIO3V3
VDD1V8AON
HIGHER CURRENT NEEDED
500mA or more

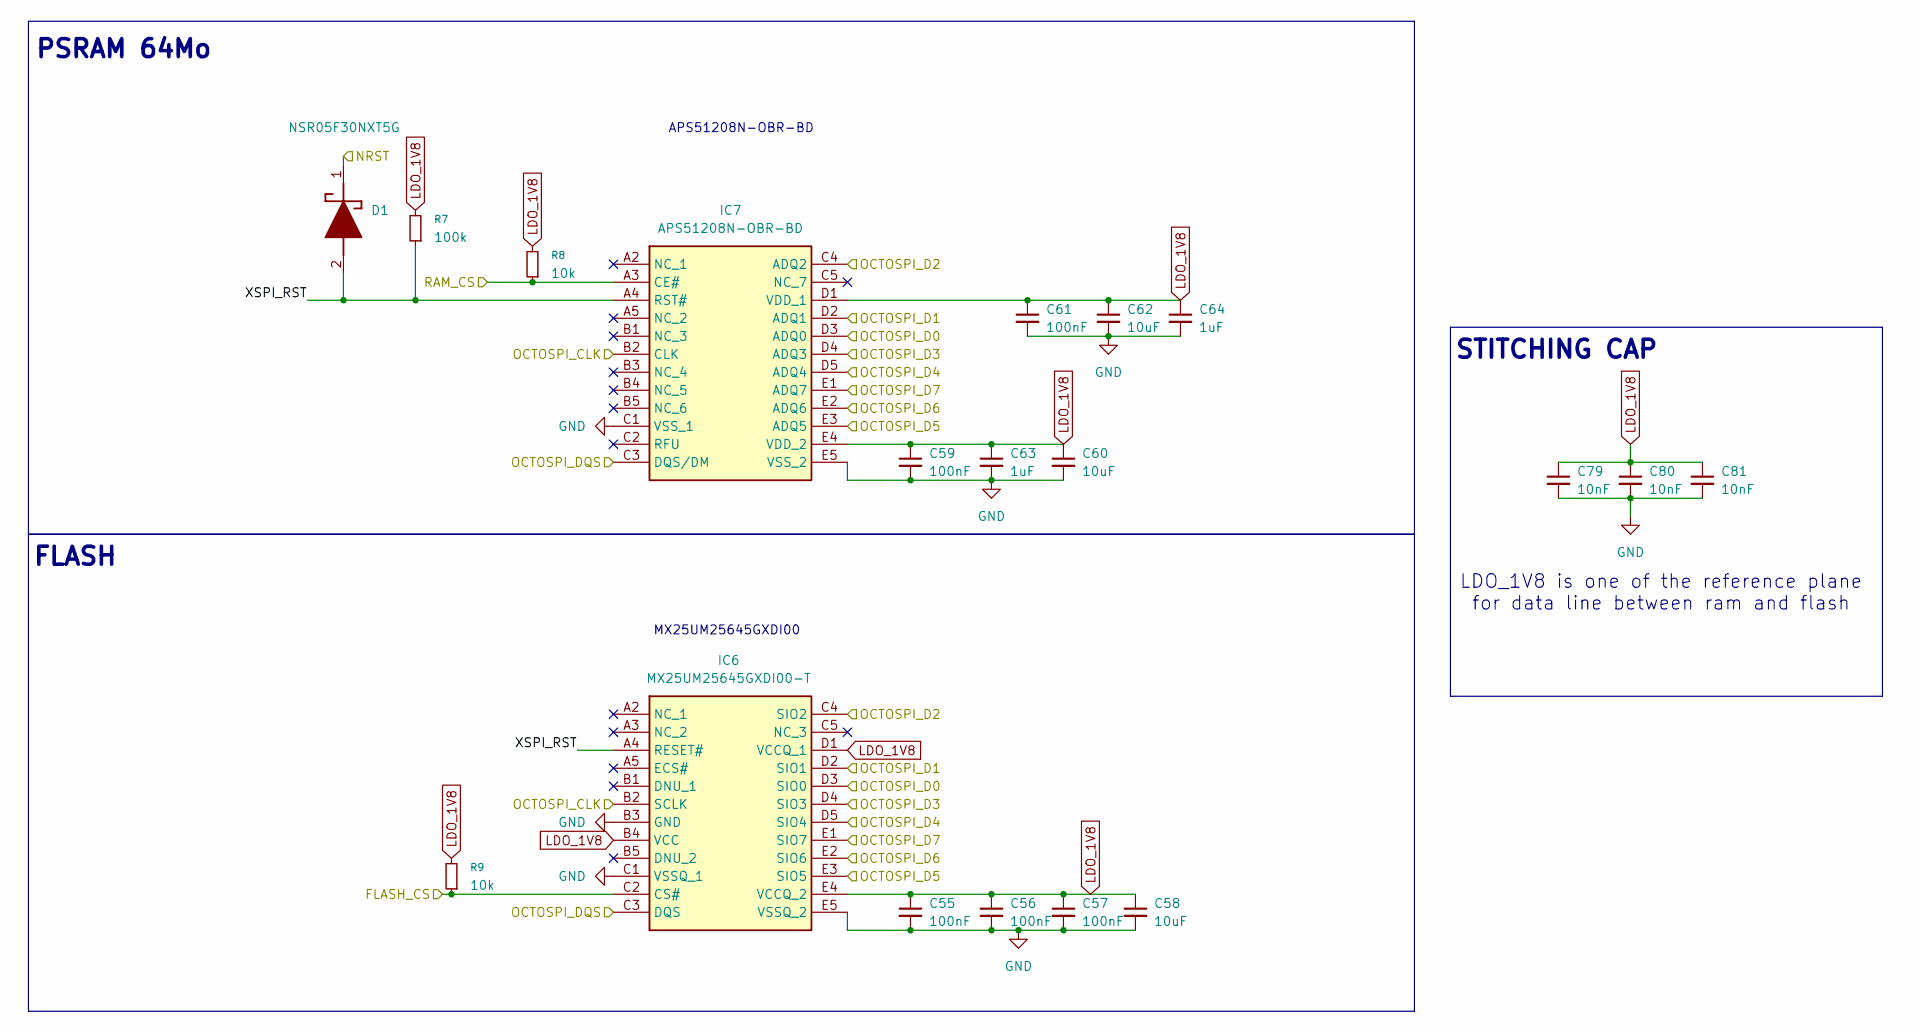
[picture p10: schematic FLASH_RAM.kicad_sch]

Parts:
C55, C56, C57, C59, C61: 100nF; C_0201_0603Metric_Pad0.64x0.40mm_HandSolder
C58, C60, C62: 10uF; C_0402_1005Metric_Pad0.74x0.62mm_HandSolder
C63, C64: 1uF; C_0201_0603Metric_Pad0.64x0.40mm_HandSolder
C79, C80, C81: 10nF; C_0201_0603Metric_Pad0.64x0.40mm_HandSolder
D1: NSR05F30NXT5G; Manufacturer_Part_Number NSR05F30NXT5G; Mouser Part Number 863-NSR05F30NXT5G
IC6: MX25UM25645GXDI00-T; BGA24C100P5X5_600X800X120; Manufacturer_Part_Number MX25UM25645GXDI00-T; Mouser Part Number 95-25UM25645GXDI0T
IC7: APS51208N-OBR-BD; BGA24C100P5X5_600X800X120; Manufacturer_Part_Number APS51208N-OBR-BD; Mouser Part Number 878-APS51208N-OBR-BD
R7: 100k; R_0201_0603Metric_Pad0.64x0.40mm_HandSolder
R8, R9: 10k; R_0201_0603Metric_Pad0.64x0.40mm_HandSolder

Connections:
/FLASH_CS: IC6.C2 (CS#), R9.1; also elsewhere on the board
/FLASH_RAM/XSPI_RST: D1.2 (A), IC6.A4 (RESET#), IC7.A4 (RST#), R7.1
/NRST: D1.1 (K); also elsewhere on the board
/OCTOSPI_CLK: IC6.B2 (SCLK), IC7.B2 (CLK); also elsewhere on the board
/OCTOSPI_D0: IC6.D3 (SIO0), IC7.D3 (ADQ0); also elsewhere on the board
/OCTOSPI_D1: IC6.D2 (SIO1), IC7.D2 (ADQ1); also elsewhere on the board
/OCTOSPI_D2: IC6.C4 (SIO2), IC7.C4 (ADQ2); also elsewhere on the board
/OCTOSPI_D3: IC6.D4 (SIO3), IC7.D4 (ADQ3); also elsewhere on the board
/OCTOSPI_D4: IC6.D5 (SIO4), IC7.D5 (ADQ4); also elsewhere on the board
/OCTOSPI_D5: IC6.E3 (SIO5), IC7.E3 (ADQ5); also elsewhere on the board
/OCTOSPI_D6: IC6.E2 (SIO6), IC7.E2 (ADQ6); also elsewhere on the board
/OCTOSPI_D7: IC6.E1 (SIO7), IC7.E1 (ADQ7); also elsewhere on the board
/OCTOSPI_DQS: IC6.C3 (DQS), IC7.C3 (DQS/DM); also elsewhere on the board
/RAM_CS: IC7.A3 (CE#), R8.1; also elsewhere on the board
GND: C55.2, C56.2, C57.2, C58.2, C59.2, C60.2, C61.2, C62.2, C63.2, C64.2, C79.2, C80.2, C81.2, IC6.B3 (GND), IC6.C1 (VSSQ_1), IC6.E5 (VSSQ_2), IC7.C1 (VSS_1), IC7.E5 (VSS_2); also elsewhere on the board
LDO_1V8: C55.1, C56.1, C57.1, C58.1, C59.1, C60.1, C61.1, C62.1, C63.1, C64.1, C79.1, C80.1, C81.1, IC6.B4 (VCC), IC6.D1 (VCCQ_1), IC6.E4 (VCCQ_2), IC7.D1 (VDD_1), IC7.E4 (VDD_2), R7.2, R8.2, R9.2; also elsewhere on the board

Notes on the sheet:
APS51208N-OBR-BD
PSRAM 64Mo
FLASH
STITCHING CAP
MX25UM25645GXDI00
LDO_1V8 is one of the reference plane for data line between ram and flash

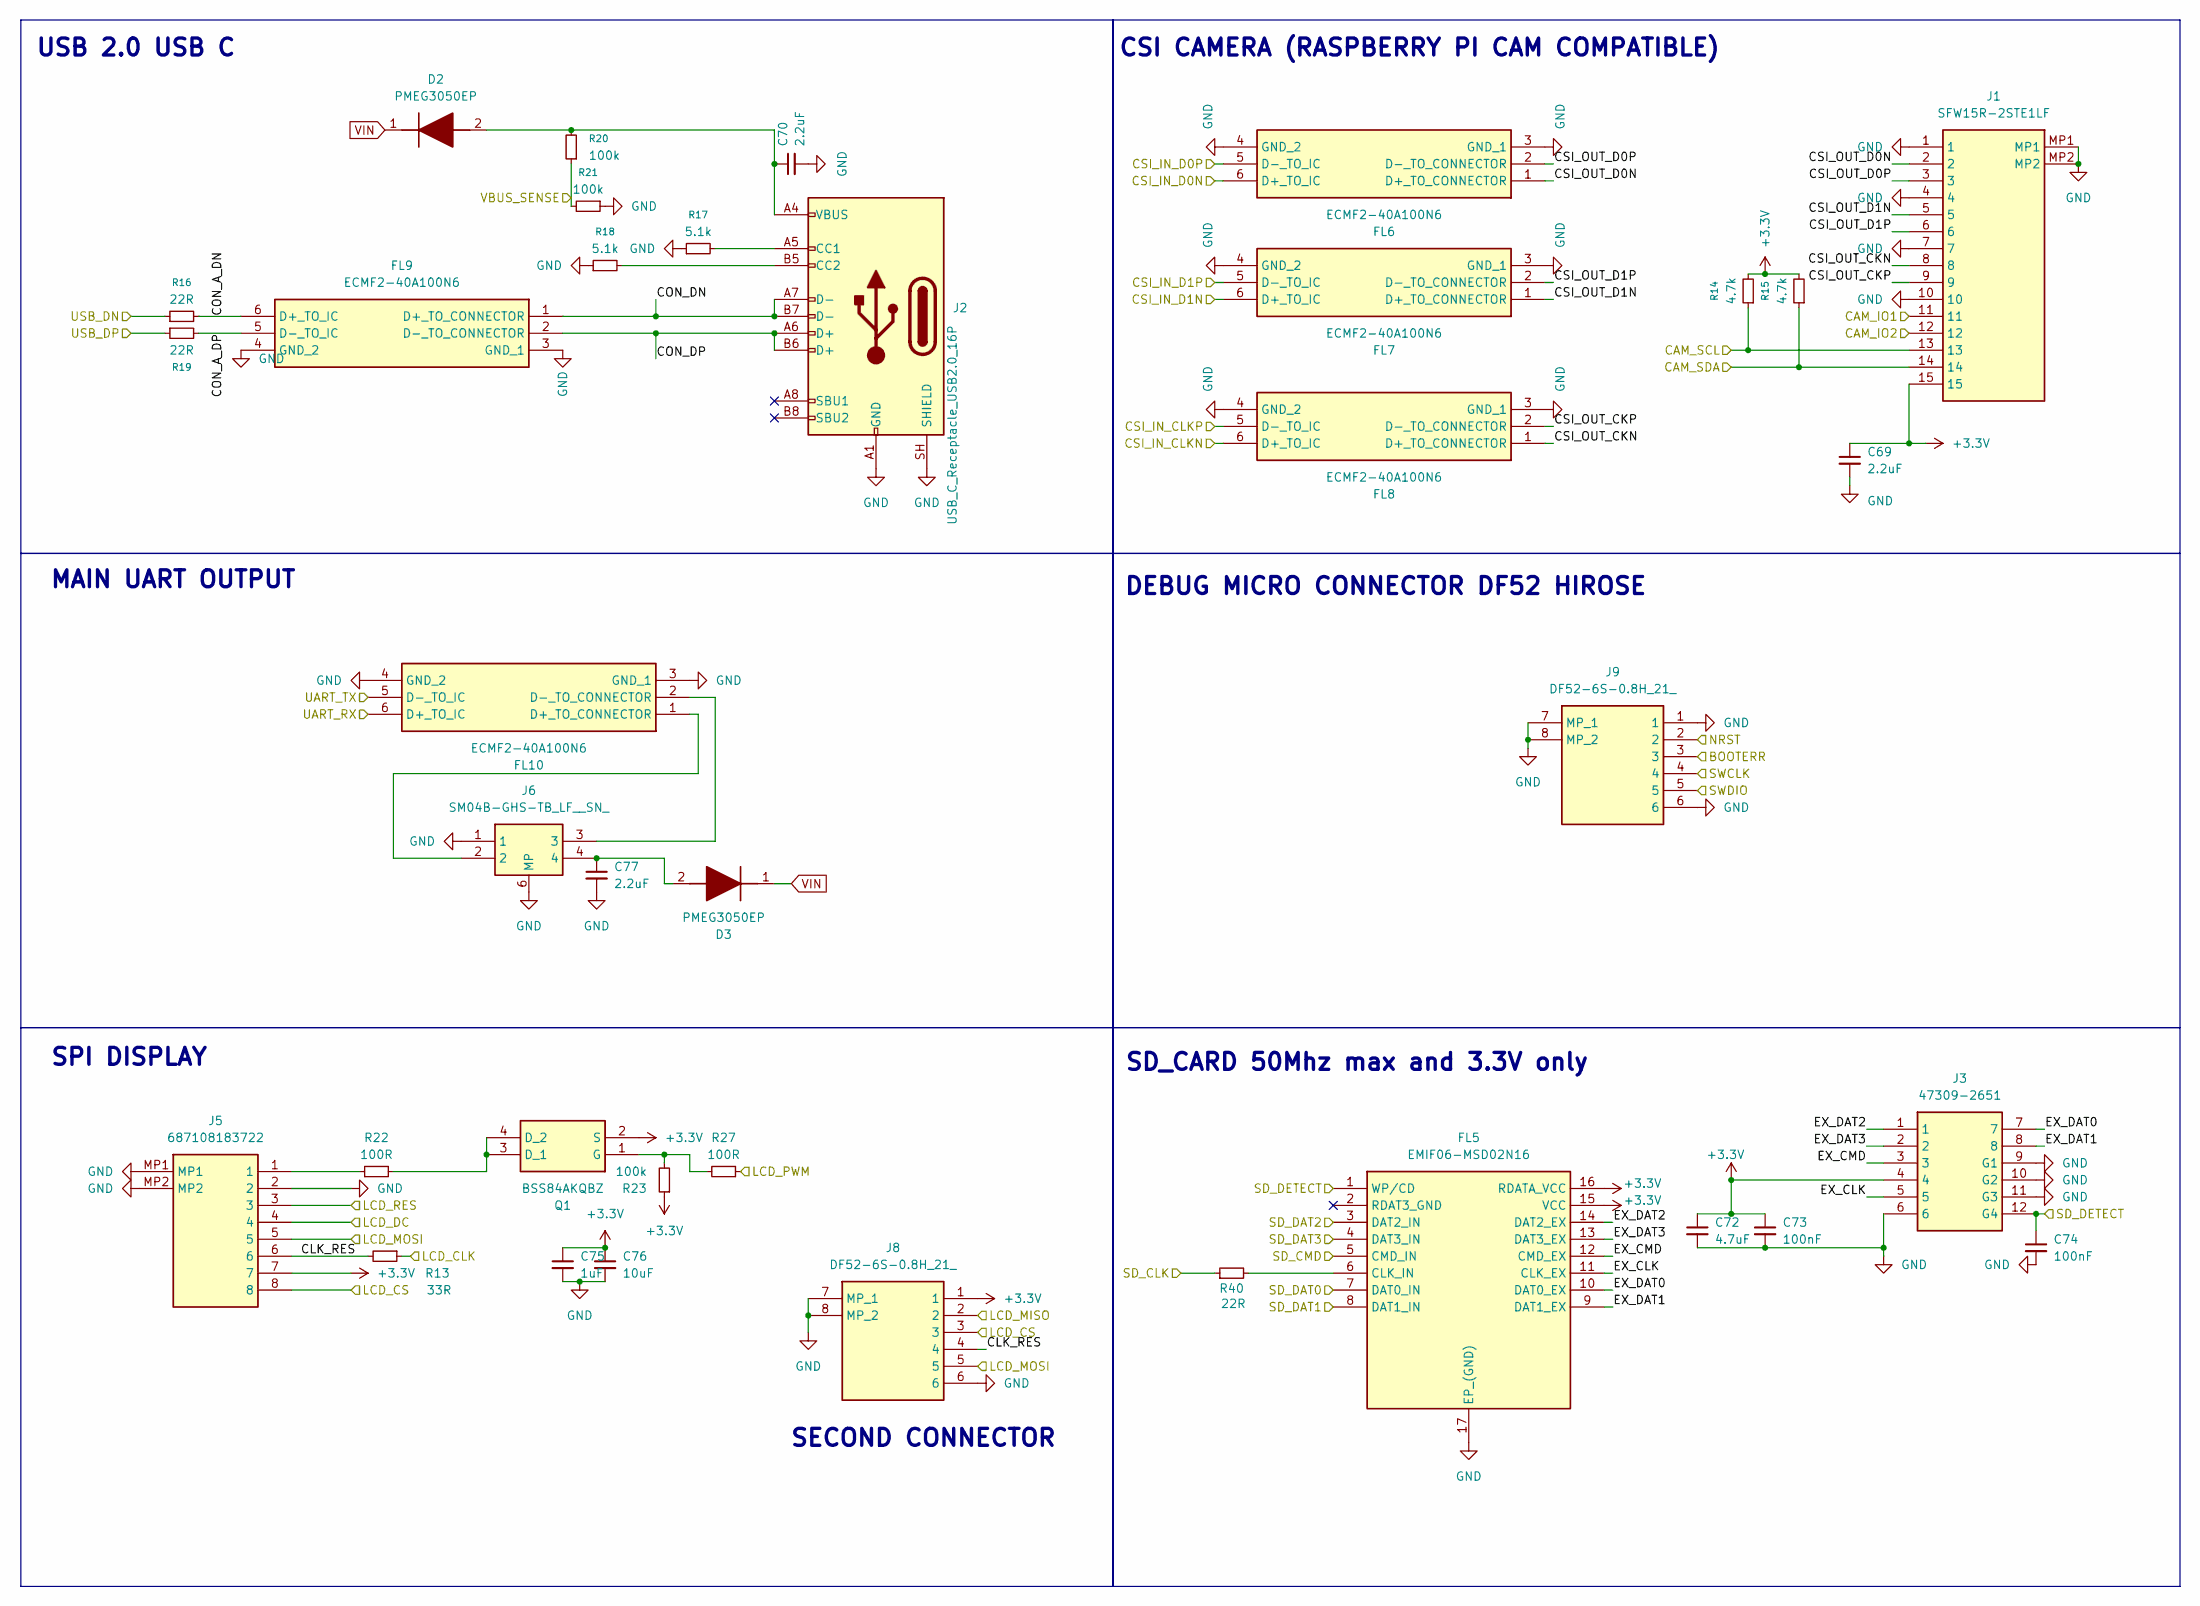
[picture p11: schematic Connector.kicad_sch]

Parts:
C69, C70, C77: 2.2uF; C_0402_1005Metric_Pad0.74x0.62mm_HandSolder
C72: 4.7uF; C_0402_1005Metric_Pad0.74x0.62mm_HandSolder
C73, C74: 100nF; C_0201_0603Metric_Pad0.64x0.40mm_HandSolder
C75: 1uF; C_0201_0603Metric_Pad0.64x0.40mm_HandSolder
C76: 10uF; C_0402_1005Metric_Pad0.74x0.62mm_HandSolder
D2, D3: PMEG3050EP; SOD4725X110N; Manufacturer_Part_Number PMEG3050EP; Mouser Part Number 771-PMEG3050EP115
FL5: EMIF06-MSD02N16; EMIF06MSD02N16; Manufacturer_Part_Number EMIF06-MSD02N16; Mouser Part Number 511-EMIF06-MSD02N16
FL6, FL7, FL8, FL9, FL10: ECMF2-40A100N6; ECMF240A100N6; Manufacturer_Part_Number ECMF2-40A100N6; Mouser Part Number 511-ECMF2-40A100N6
J1: SFW15R-2STE1LF; SFW15R2STE1LF; Manufacturer_Part_Number SFW15R-2STE1LF; Mouser Part Number 649-SFW15R-2STE1LF
J2: USB_C_Receptacle_USB2.0_16P; USB_C_Receptacle_GCT_USB4110; Mouser Part Number 640-USB4110-GF-A
J3: 47309-2651; 473092651; Manufacturer_Part_Number 47309-2651; Mouser Part Number 538-47309-2651
J5: 687108183722; Mouser Part Number 710-687108183722
J6: SM04B-GHS-TB_LF__SN_; SM04B-GHS-TB; Manufacturer_Part_Number SM04B-GHS-TB(LF)(SN); Mouser Part Number 306-SM04BGHSTBLFSN
J8, J9: DF52-6S-0.8H_21_; DF526S08H21; Manufacturer_Part_Number DF52-6S-0.8H(21); Mouser Part Number 798-DF52-6S-0.8H21
Q1: BSS84AKQBZ; 2N7002KQBZ; Mouser Part Number 771-2N7002KQBZ
R13: 33R; R_0201_0603Metric_Pad0.64x0.40mm_HandSolder
R14, R15: 4.7k; R_0201_0603Metric_Pad0.64x0.40mm_HandSolder
R16, R19, R40: 22R; R_0201_0603Metric_Pad0.64x0.40mm_HandSolder
R17, R18: 5.1k; R_0201_0603Metric_Pad0.64x0.40mm_HandSolder
R20, R21, R23: 100k; R_0201_0603Metric_Pad0.64x0.40mm_HandSolder
R22, R27: 100R; R_0201_0603Metric_Pad0.64x0.40mm_HandSolder

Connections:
+3.3V: C69.1, C72.1, C73.1, C75.1, C76.1, FL5.15 (VCC), FL5.16 (RDATA_VCC), J1.15, J3.4, J5.7, J8.1, Q1.2 (S), R14.2, R15.2, R23.1; also elsewhere on the board
/BOOT_ERROR: J9.3; also elsewhere on the board
/CAM_IO1: J1.11; also elsewhere on the board
/CAM_IO2: J1.12; also elsewhere on the board
/CAM_SCL: J1.13, R14.1; also elsewhere on the board
/CAM_SDA: J1.14, R15.1; also elsewhere on the board
/CSI_CKN: FL8.6 (D+_TO_IC); also elsewhere on the board
/CSI_CKP: FL8.5 (D-_TO_IC); also elsewhere on the board
/CSI_D0N: FL6.6 (D+_TO_IC); also elsewhere on the board
/CSI_D0P: FL6.5 (D-_TO_IC); also elsewhere on the board
/CSI_D1N: FL7.6 (D+_TO_IC); also elsewhere on the board
/CSI_D1P: FL7.5 (D-_TO_IC); also elsewhere on the board
/Connector/CLK_RES: J5.6, J8.4, R13.2
/Connector/CON_A_DN: FL9.6 (D+_TO_IC), R16.2
/Connector/CON_A_DP: FL9.5 (D-_TO_IC), R19.2
/Connector/CON_DN: FL9.1 (D+_TO_CONNECTOR), J2.A7 (D-), J2.B7 (D-)
/Connector/CON_DP: FL9.2 (D-_TO_CONNECTOR), J2.A6 (D+), J2.B6 (D+)
/Connector/CSI_OUT_CKN: FL8.1 (D+_TO_CONNECTOR), J1.8
/Connector/CSI_OUT_CKP: FL8.2 (D-_TO_CONNECTOR), J1.9
/Connector/CSI_OUT_D0N: FL6.1 (D+_TO_CONNECTOR), J1.2
/Connector/CSI_OUT_D0P: FL6.2 (D-_TO_CONNECTOR), J1.3
/Connector/CSI_OUT_D1N: FL7.1 (D+_TO_CONNECTOR), J1.5
/Connector/CSI_OUT_D1P: FL7.2 (D-_TO_CONNECTOR), J1.6
/Connector/EX_CLK: FL5.11 (CLK_EX), J3.5
/Connector/EX_CMD: FL5.12 (CMD_EX), J3.3
/Connector/EX_DAT0: FL5.10 (DAT0_EX), J3.7
/Connector/EX_DAT1: FL5.9 (DAT1_EX), J3.8
/Connector/EX_DAT2: FL5.14 (DAT2_EX), J3.1
/Connector/EX_DAT3: FL5.13 (DAT3_EX), J3.2
/LCD_CLK: R13.1; also elsewhere on the board
/LCD_CS: J5.8, J8.3; also elsewhere on the board
/LCD_DC: J5.4; also elsewhere on the board
/LCD_MISO: J8.2; also elsewhere on the board
/LCD_MOSI: J5.5, J8.5; also elsewhere on the board
/LCD_PWM: R27.1; also elsewhere on the board
/LCD_RES: J5.3; also elsewhere on the board
/NRST: J9.2; also elsewhere on the board
/SD_CLK: R40.1; also elsewhere on the board
/SD_CMD: FL5.5 (CMD_IN); also elsewhere on the board
/SD_DAT0: FL5.7 (DAT0_IN); also elsewhere on the board
/SD_DAT1: FL5.8 (DAT1_IN); also elsewhere on the board
/SD_DAT2: FL5.3 (DAT2_IN); also elsewhere on the board
/SD_DAT3: FL5.4 (DAT3_IN); also elsewhere on the board
/SD_DETECT: C74.1, FL5.1 (WP/CD), J3.12 (G4); also elsewhere on the board
/SWCLK: J9.4; also elsewhere on the board
/SWDIO: J9.5; also elsewhere on the board
/USART6_RX: FL10.6 (D+_TO_IC); also elsewhere on the board
/USART6_TX: FL10.5 (D-_TO_IC); also elsewhere on the board
/USB1_DN: R16.1; also elsewhere on the board
/USB1_DP: R19.1; also elsewhere on the board
/USB_VBUS_SENSE: R20.1, R21.2; also elsewhere on the board
GND: C69.2, C70.2, C72.2, C73.2, C74.2, C75.2, C76.2, C77.2, FL5.17 (EP_(GND)), FL6.3 (GND_1), FL6.4 (GND_2), FL7.3 (GND_1), FL7.4 (GND_2), FL8.3 (GND_1), FL8.4 (GND_2), FL9.3 (GND_1), FL9.4 (GND_2), FL10.3 (GND_1), FL10.4 (GND_2), J1.1, J1.4, J1.7, J1.10, J1.MP1, J1.MP2, J2.A1 (GND), J2.A12 (GND), J2.B1 (GND), J2.B12 (GND), J2.SH (SHIELD), J3.6, J3.9 (G1), J3.10 (G2), J3.11 (G3), J5.2, J5.MP1, J5.MP2, J6.1, J6.5 (MP), J6.6 (MP), J8.6, J8.7 (MP_1), J8.8 (MP_2), J9.1, J9.6, J9.7 (MP_1), J9.8 (MP_2), R17.1, R18.1, R21.1; also elsewhere on the board
unnamed: C70.1, D2.2 (A), J2.A4 (VBUS), J2.A9 (VBUS), J2.B4 (VBUS), J2.B9 (VBUS), R20.2
unnamed: C77.1, D3.2 (A), J6.4
unnamed: FL5.6 (CLK_IN), R40.2
unnamed: FL10.1 (D+_TO_CONNECTOR), J6.2
unnamed: FL10.2 (D-_TO_CONNECTOR), J6.3
unnamed: J2.A5 (CC1), R17.2
unnamed: J2.B5 (CC2), R18.2
unnamed: J5.1, R22.1
unnamed: Q1.3 (D_1), Q1.4 (D_2), R22.2
unnamed: Q1.1 (G), R23.2, R27.2
VIN: D2.1 (K), D3.1 (K); also elsewhere on the board

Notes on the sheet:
MAIN UART OUTPUT
USB 2.0 USB C
SD_CARD 50Mhz max and 3.3V only
DEBUG MICRO CONNECTOR DF52 HIROSE
CSI CAMERA (RASPBERRY PI CAM COMPATIBLE)
SECOND CONNECTOR
SPI DISPLAY

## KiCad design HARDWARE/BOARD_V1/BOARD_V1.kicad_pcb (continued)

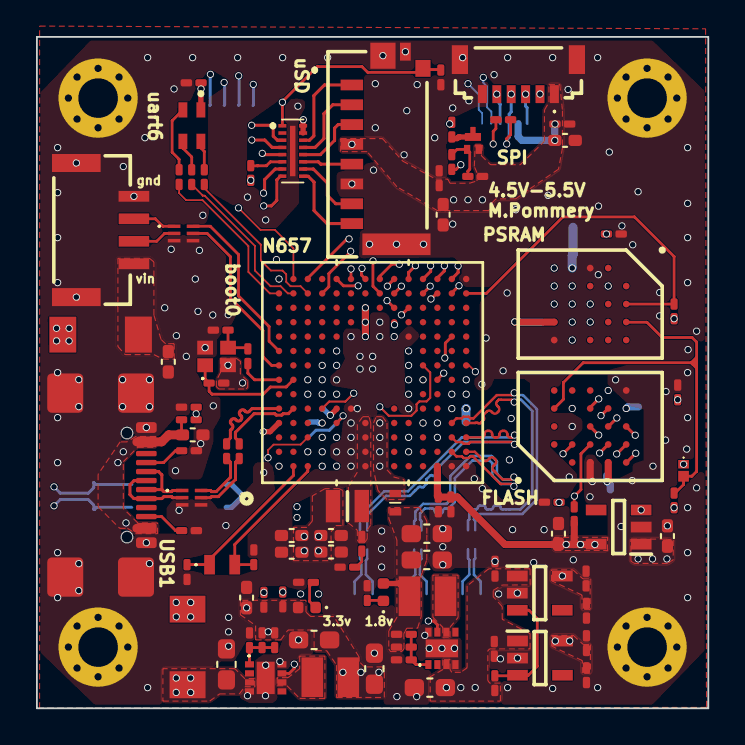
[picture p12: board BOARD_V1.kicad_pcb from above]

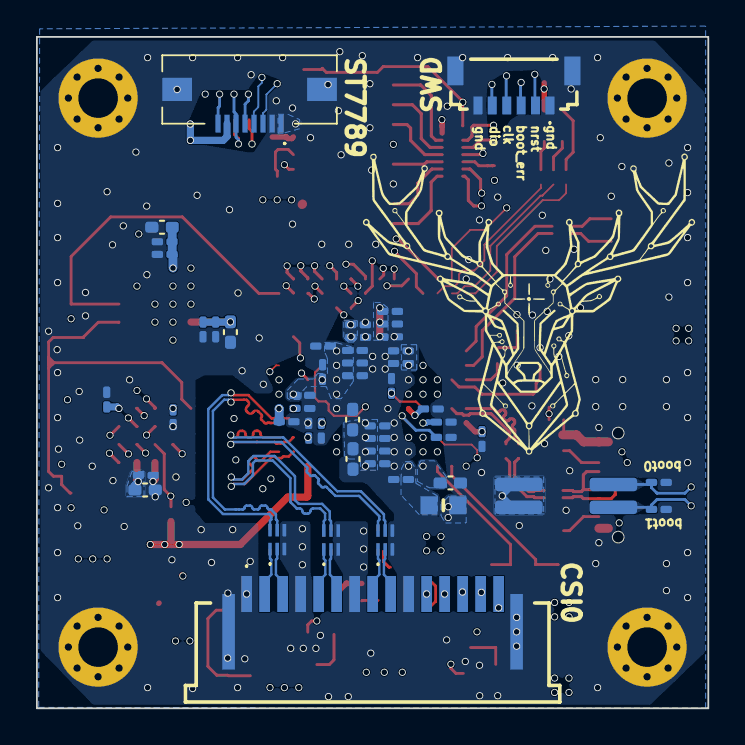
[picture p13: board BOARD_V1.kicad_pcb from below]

Board: 8 copper layers, 37.3 x 37.3 mm, 149 parts (50 on the bottom side), 109 nets.

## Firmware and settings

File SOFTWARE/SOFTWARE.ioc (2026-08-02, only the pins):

Mcu.UserName=STM32N657I0HxQ
PA13(JTMS/SWDIO).Signal=DEBUG_JTMS-SWDIO
PA14(JTCK/SWCLK).Signal=DEBUG_JTCK-SWCLK
PA6.Signal=BOOT1
PB5(JTDO/TRACESWO).Signal=DEBUG_JTDO-SWO
PD3.GPIO_Label=BLUE
PD3.Signal=GPIO_Output
PD4.GPIO_Label=GREEN
PD4.Signal=GPIO_Output
PE8.GPIO_Label=RED
PE8.Signal=GPIO_Output
PH0-OSC_IN(PH0).Signal=RCC_OSC_IN
PH1-OSC_OUT(PH1).Signal=RCC_OSC_OUT

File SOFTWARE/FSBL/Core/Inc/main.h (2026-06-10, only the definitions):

#define BLUE_Pin GPIO_PIN_3
#define BLUE_GPIO_Port GPIOD
#define GREEN_Pin GPIO_PIN_4
#define GREEN_GPIO_Port GPIOD
#define RED_Pin GPIO_PIN_8
#define RED_GPIO_Port GPIOE

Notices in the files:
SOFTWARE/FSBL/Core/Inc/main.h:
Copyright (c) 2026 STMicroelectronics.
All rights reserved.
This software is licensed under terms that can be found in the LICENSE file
